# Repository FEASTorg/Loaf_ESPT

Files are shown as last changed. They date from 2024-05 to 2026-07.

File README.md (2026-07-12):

# Loaf ESPT

ESP32 Thing Plus controller Loaf for building a BREAD from compatible Slices.

## Introduction

This Loaf serves as the supervisory controller and interconnect for one or more Slices. The design includes bus connectors, an ESP32 Thing Plus, a 12V to 5V regulator, 3.3V to 5V logic level shifting, and I2C level shifting and acceleration.

## Usage

[Explain how to use the project. Include examples and screenshots if applicable.]

## Documentation

Please refer to the [docs](/docs) for more info.

---

<div align="center">
  <p>
    
    
  </p>
</div>

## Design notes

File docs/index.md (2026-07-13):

---
title: "Loaf ESPT Documentation"
description: "Overview and entry page for Loaf ESPT project documentation."
nav_exclude: true
---

Welcome to the Loaf ESPT project documentation.

## Board Renders

<figure style="display:inline-block; text-align:center; margin:10px;">
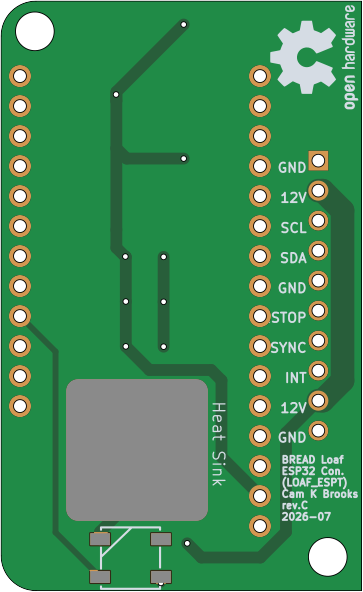
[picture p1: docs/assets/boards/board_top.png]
Board Top
  
  <figcaption>Top</figcaption>
</figure>

<figure style="display:inline-block; text-align:center; margin:10px;">
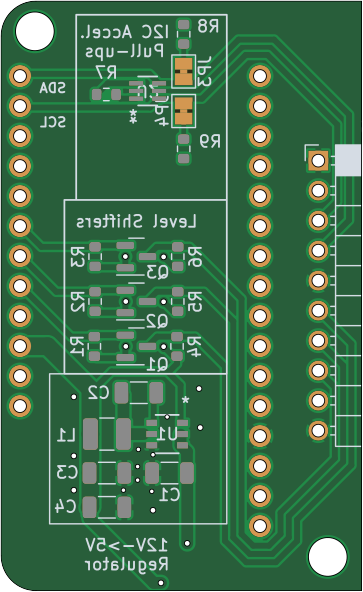
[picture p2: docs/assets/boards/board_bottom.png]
Board Bottom
  
  <figcaption>Bottom</figcaption>
</figure>

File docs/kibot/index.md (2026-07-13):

Loaf ESPT KiBot Outputs
============================

Generated: 2026-07-13 at 04:44:23 UTC

## Artifacts

- [Schematic.pdf](./Schematic.pdf)
- [PCB.pdf](./PCB.pdf)
- [kibot.log](./kibot.log)
- [BREAD_Loaf-bom.html](./BREAD_Loaf-bom.html)
- [BREAD_Loaf-ibom.html](./BREAD_Loaf-ibom.html)

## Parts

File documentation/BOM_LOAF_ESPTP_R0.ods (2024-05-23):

References | Value | Footprint | Quantity | URL | Alternate
C1, C3, C4 | 22uF | C_1206_3216Metric | 3 | https://www.digikey.ca/en/products/detail/samsung-electro-mechanics/CL31A226KAHNNNE/3888705
C2 | 100nF | C_1206_3216Metric | 1 | https://www.digikey.ca/en/products/detail/samsung-electro-mechanics/CL31B104KBCNNNC/3886675
R1, R2, R3, R4, R5, R6, R7 | 10k | R_0603_1608Metric | 7 | https://www.digikey.ca/en/products/detail/stackpole-electronics-inc/RMCF0603FT10K0/1761235
R9, R11 | 4.7k | R_0603_1608Metric | 2 | https://www.digikey.ca/en/products/detail/stackpole-electronics-inc/RMCF0603FT4K70/1760998
R10, R12 | 2.2k | R_0603_1608Metric | 2 | https://www.digikey.ca/en/products/detail/yageo/RC0603JR-132K2L/14286397
R8 | 200k | R_0603_1608Metric | 1 | https://www.digikey.ca/en/products/detail/stackpole-electronics-inc/RMCF0603FT200K/1760715
L1 | 4.7uH | L_1210_3225Metric | 1 | https://www.digikey.ca/en/products/detail/tdk-corporation/BCL322520RT-4R7M-D/15849704
U1 | LTC4311ISC6-TRMPBF | SOT-363_SC-70-6 | 1 | https://www.digikey.ca/en/products/detail/analog-devices-inc/LTC4311ISC6-TRMPBF/1814493
U2 | AP63205WU-7 | TSOT-23-6 | 1 | https://www.digikey.ca/en/products/detail/diodes-incorporated/AP63205WU-7/9858424
U3 | PCA9306 | SSOP-8_2.95x2.8mm_P0.65mm | 1 | https://www.digikey.ca/en/products/detail/texas-instruments/PCA9306DCUR/768359
Q1, Q2, Q3 | BSS138 | SOT-23 | 3 | https://www.digikey.ca/en/products/detail/diodes-incorporated/BSS138-7-F/717843?productid=717843&gad_source=1
HS1 | Heatsink_Pad (optional) | Thermal Pad | 1 | https://www.digikey.ca/en/products/detail/assmann-wsw-components/V2017B/3511410
J2 | THING_PLUS_LOGICAL | ESP_THING_PLUS | 1 | https://www.sparkfun.com/products/20168 | https://www.digikey.ca/en/products/detail/sparkfun-electronics/WRL-20168/16688100
J6 | PPTC101LGBN-RC | PinSocket_1x10_P2.54mm_Horizontal | 1 | https://www.digikey.ca/en/products/detail/sullins-connector-solutions/PPTC101LGBN-RC/775904

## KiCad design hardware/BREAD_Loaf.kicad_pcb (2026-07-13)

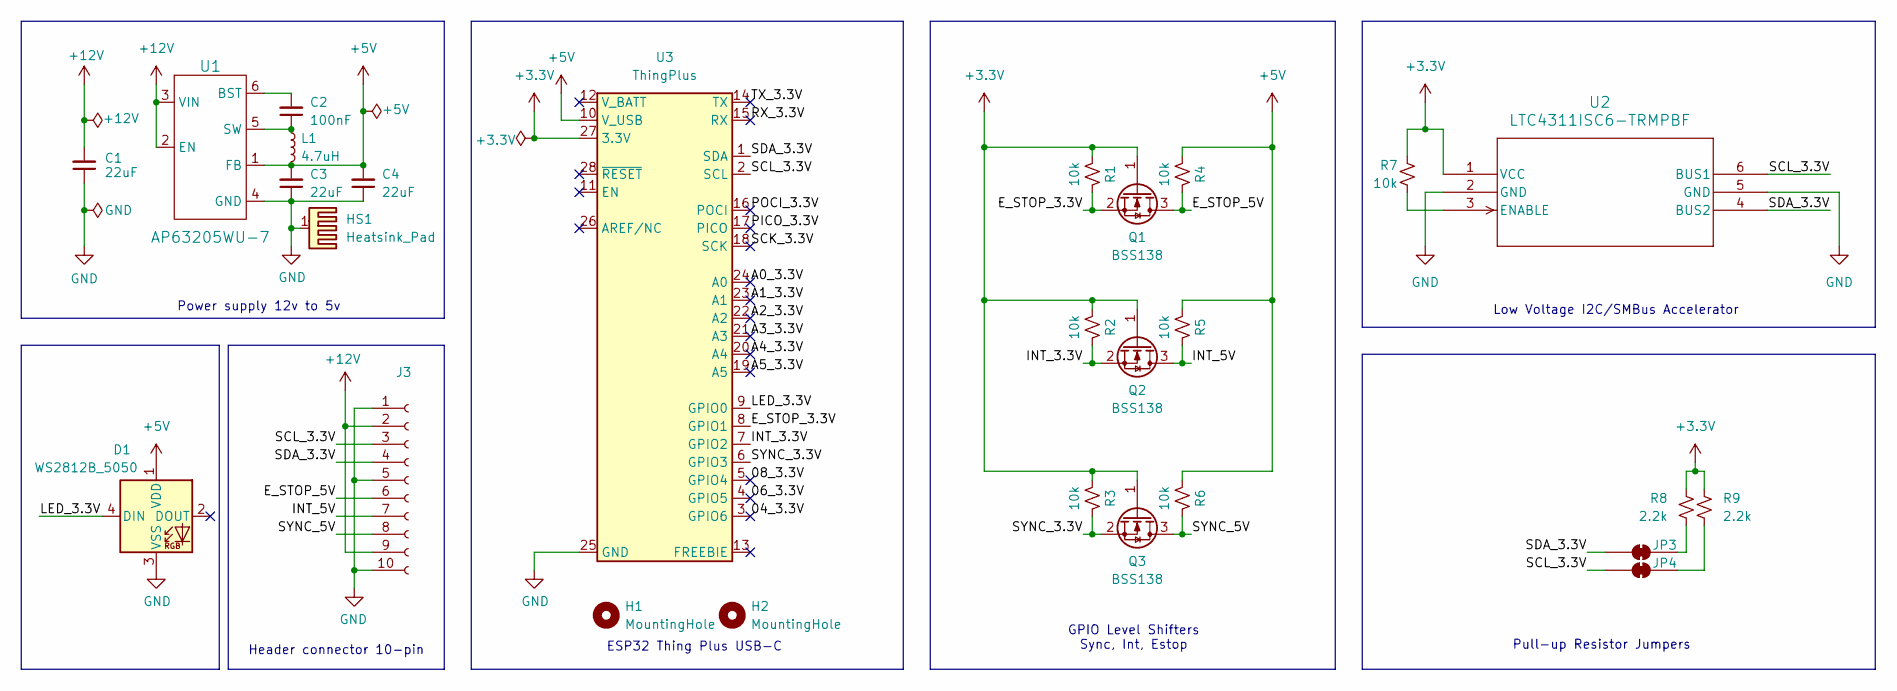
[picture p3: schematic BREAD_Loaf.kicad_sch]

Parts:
C1, C3, C4: 22uF; C_1206_3216Metric
C2: 100nF; C_1206_3216Metric
D1: WS2812B_5050; WS2812-5050-4PIN
H1, H2: MountingHole; MountingHole_3.2mm_M3
HS1: Heatsink_Pad; Thermal_Pad
J3: Conn_01x10_Socket; PinSocket_1x10_P2.54mm_Horizontal
JP3, JP4: SolderJumper_2_Bridged; SolderJumper-2_P1.3mm_Bridged_Pad1.0x1.5mm
L1: 4.7uH; L_1210_3225Metric
Q1, Q2, Q3: BSS138; SOT-23
R1, R2, R3, R4, R5, R6, R7: 10k; R_0603_1608Metric
R8, R9: 2.2k; R_0603_1608Metric
U1: AP63205WU-7; SOIC_05WU-7_DIO
U2: LTC4311ISC6-TRMPBF; SOT-6_SC_LIT
U3: ThingPlus; ThingPlus_With_Connectors

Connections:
+3.3V: Q1.1 (G), Q2.1 (G), Q3.1 (G), R1.2, R2.2, R3.2, R7.1, R8.1, R9.1, U2.1 (VCC), U3.27 (3.3V)
+5V: C3.2, C4.2, D1.1 (VDD), L1.2, R4.2, R5.2, R6.2, U1.1 (FB), U3.10 (V_USB)
+12V: C1.2, J3.2, J3.9, U1.2 (EN), U1.3 (VIN)
/04_3.3V: U3.3 (GPIO6)
/06_3.3V: U3.4 (GPIO5)
/08_3.3V: U3.5 (GPIO4)
/A0_3.3V: U3.24 (A0)
/A1_3.3V: U3.23 (A1)
/A2_3.3V: U3.22 (A2)
/A3_3.3V: U3.21 (A3)
/A4_3.3V: U3.20 (A4)
/A5_3.3V: U3.19 (A5)
/E_STOP_3.3V: Q1.2 (S), R1.1, U3.8 (GPIO1)
/E_STOP_5V: J3.6, Q1.3 (D), R4.1
/INT_3.3V: Q2.2 (S), R2.1, U3.7 (GPIO2)
/INT_5V: J3.7, Q2.3 (D), R5.1
/LED_3.3V: D1.4 (DIN), U3.9 (GPIO0)
/PICO_3.3V: U3.17 (PICO)
/POCI_3.3V: U3.16 (POCI)
/RX_3.3V: U3.15 (RX)
/SCK_3.3V: U3.18 (SCK)
/SCL_3.3V: J3.3, JP4.1 (A), U2.6 (BUS1), U3.2 (SCL)
/SDA_3.3V: J3.4, JP3.1 (A), U2.4 (BUS2), U3.1 (SDA)
/SYNC_3.3V: Q3.2 (S), R3.1, U3.6 (GPIO3)
/SYNC_5V: J3.8, Q3.3 (D), R6.1
/TX_3.3V: U3.14 (TX)
GND: C1.1, C3.1, C4.1, D1.3 (VSS), HS1.1, J3.1, J3.5, J3.10, U1.4 (GND), U2.2 (GND), U2.5 (GND), U3.25 (GND)
unnamed: JP3.2 (B), R8.2
unnamed: JP4.2 (B), R9.2
unnamed: C2.2, U1.6 (BST)
unnamed: C2.1, L1.1, U1.5 (SW)
unnamed: R7.2, U2.3 (ENABLE)

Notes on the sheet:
Power supply 12v to 5v
Header connector 10-pin
Low Voltage I2C/SMBus Accelerator
GPIO Level Shifters Sync, Int, Estop
ESP32 Thing Plus USB-C
Pull-up Resistor Jumpers

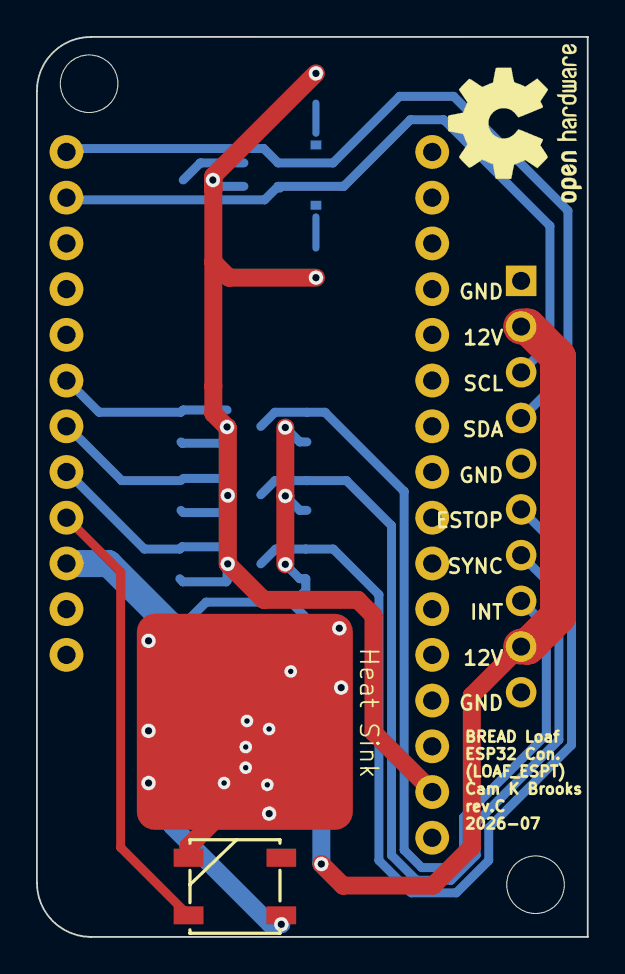
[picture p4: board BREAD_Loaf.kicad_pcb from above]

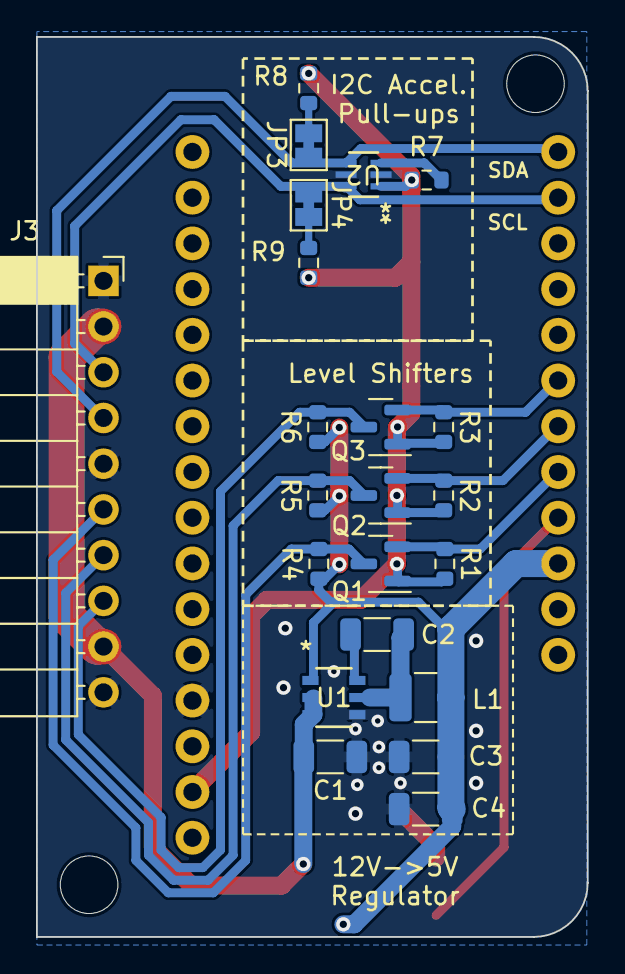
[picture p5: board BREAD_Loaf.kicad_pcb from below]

Board: 2 copper layers, 30.6 x 50.0 mm, 27 parts (22 on the bottom side), 18 nets.

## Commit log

2024-08-30 updated outputs for fab
    [BREAD_Loaf-B_Cu.gbr, BREAD_Loaf-B_Mask.gbr, BREAD_Loaf-B_Paste.gbr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]
2024-08-31 added art and cleared erc errors
    [BREAD_Loaf-B_Cu.gbr, BREAD_Loaf-B_Mask.gbr, BREAD_Loaf-B_Paste.gbr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]
2024-09-27 updated to remove i2c shifter and optimized layout
    [BREAD_Loaf-B_Cu.gbr, BREAD_Loaf-B_Mask.gbr, BREAD_Loaf-B_Paste.gbr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]
2024-09-30 JLCPCB order rev-A
    [BREAD_Loaf-B_Cu.gbr, BREAD_Loaf-B_Mask.gbr, BREAD_Loaf-B_Paste.gbr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]
2026-07-12 chore(hw): migrate KiCad files to the KiCad 10 format
    Via `kicad-cli sch upgrade` / `pcb upgrade` (bread-infra
    scripts/upgrade_kicad10.sh). Verified lossless: identical netlist, footprint
    positions and routing.
    Note `sch upgrade` does not cascade into hierarchical sub-sheets, so every
    .kicad_sch is upgraded individually -- upgrading only the root sheet leaves
    sub-sheets on the old format, which looks migrated and is not.
    [BREAD_Loaf.kicad_pcb, BREAD_Loaf.kicad_sch]
2026-07-12 fix(hw): fail DRC on schematic/PCB footprint mismatch
    KiCad's stock default severity for footprint_symbol_mismatch is `warning`
    (board_design_settings.cpp:189), and KiBot's DRC preflight only fails on
    errors. So `schematic_parity: true` ran the check and could never fail it --
    a mismatch was reported on every CI run for months, buried in ~100 warnings,
    and every run went green.
    Raising it to `error` makes the parity gate real.
2026-07-12 chore: gitignore KiCad 10 local history
    KiCad 10 added a Local History feature. On first save it creates
    <project>/.history and calls git_repository_init() on it, so the directory is
    a nested git repository. KiCad writes a .gitignore inside it, but that governs
    KiCad's own history repo -- this repo still sees an embedded repository and
    reports it untracked. Committing it would add a broken gitlink.
2026-07-12 fix(hw): re-point stale library nicknames
    These parts exist in KiCad-Master-Lib; the boards referenced libraries that no
    longer exist (kml-custom, KML-Custom, and SparkFun libraries that never
    contained the part) or names the library has since changed.
    KiCad embeds footprint geometry in the .kicad_pcb, so the boards rendered and
    fabricated correctly and the rot stayed invisible -- it only surfaces on
    update-from-library, or when a generator tries to resolve a nickname.
    Nickname/name only. No geometry is changed:
    KML-Custom:Thermal Pad -> KMLib_Mounting:Thermal_Pad
    SparkFun-DiscreteSemi:AP63205 -> KMLib_IC_Power:AP63205WU-7_Buck_Regulator
    SparkFun-LED:WS2812-5050-4PIN -> KMLib_IC_SMD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
    [BREAD_Loaf.kicad_pcb, BREAD_Loaf.kicad_sch]
2026-07-12 chore: stop tracking .kicad_prl
    KiCad rewrites .kicad_prl on every project open -- open sheet, zoom level,
    selection filter. It is per-developer local state, not design intent, so
    tracking it means the working tree goes dirty every time anyone opens the board.
2026-07-12 ci: gate on board validation and run on pull requests
    - add the validate-board job: KiCad 10 format, a real (error-severity) DRC
    parity gate, every library reference resolving, un-swapped Makefile targets,
    and .history/.kicad_prl gitignored. Green means the board is done.
    - run on pull_request, not just push to main. Hardware checks previously ran
    only AFTER a change had merged: they could report that main was broken, but
    never stop it from breaking. A gate that only fires post-merge is a
    notification, not a gate.
    - pin bread-infra to v1.0.0 rather than @main, so a bread-infra commit cannot
    silently change what this PR is gated on.
2026-07-12 chore: gitignore KiCad 10 generated and lock files
    KiCad 10 adds design-block libraries and generates a design-block-lib-table
    alongside fp-lib-table and sym-lib-table. Like those, it holds absolute paths,
    so it is machine-local and generated -- never committed.
    Also ignores KiCad's project lock file (~<project>.kicad_pro.lck), written
    whenever a project is open.
    The existing .gitignore predates KiCad 10 and covered neither, so simply opening
    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
2026-07-12 fix(hw): repair symbol sub-unit name prefixes
    The library re-point renamed symbols in lib_symbols from LIB:OLD to LIB:NEW,
    but a symbol's sub-units carry the bare item name:
    (symbol "KMLib_IC_Power:AP63205WU-7_Buck_Regulator"
    (symbol "AP63205_0_1" ...) <- still the old prefix
    KiCad requires every sub-unit to be named "<parent item>_<unit>_<style>", so any
    symbol whose ITEM name changed (not merely its library) failed to load:
    Invalid symbol unit name prefix AP63205_0_1
    Rename each sub-unit to match its parent. Nickname-only re-points were never
    affected -- their item name is unchanged.
    Note kicad-cli reports "Failed to load schematic" and still EXITS 0, so this was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
    [BREAD_Loaf.kicad_sch]
2026-07-12 ci: pin bread-infra v1.1.0
    v1.1.0 adds the schematic-load check. kicad-cli prints 'Failed to load
    schematic' and still exits 0, so an unloadable schematic scored as zero ERC
    violations -- 34 boards were unopenable while every automated check said they
    were fine. validate-board now runs in the KiCad container and actually loads
    every sheet.
2026-07-13 fix(hw): re-point remaining library references
    Every symbol now resolves against KiCad-Master-Lib:
    LTC4311:LTC4311ISC6-TRMPBF -> KMLib_IC_Digital:LTC4311ISC6-TRMPBF
    SparkFun-RF:ESP_THING_PLUS_LOGICAL -> SparkFun-Board:ThingPlus_With_Connectors
    SparkFun-Hardware:Stand_off, PPPC101LGBN-RC, Arc -> resolved
    Board is clean: validate_board PASS, 0 ERC errors, 0 DRC errors.
    [BREAD_Loaf.kicad_pcb, BREAD_Loaf.kicad_sch]
2026-07-13 feat: add KiBot, docs and manifest infrastructure
    The Loaves were the only real boards in the fleet with no automated checking at
    all: no Makefile, no KiBot config, no docs site, no manifest. Every Slice has had
    all four for months.
    - hardware/Makefile, hardware/config.kibot.yaml (canonical 2-layer) -- ERC, DRC
    and fab outputs now run in CI
    - loaf.yaml + .github/workflows/ci.yml -- manifest validated against
    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
2026-07-13 📄 KiBot index + board renders (auto)
